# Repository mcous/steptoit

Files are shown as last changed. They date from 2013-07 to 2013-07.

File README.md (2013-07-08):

# Stepper Driver Board

## Parts to research / use
* Stepper driver - TI DRV8834
    * Up to 1/32 microstepping
    * 1.5 A continuous, 2.2 A peak
    * Step / direction control
    * Digikey qty 1: QFN: $2.98, TSOP: $3.53
* MCU - AVR ATMega328P
    * Cheap, simple, known
    * Probably underpowered in the long term
    * Tops out (apparently) at 16 MHz, and would like to go faster
* Steppers
    * check out http://www.mpja.com/
    * Start small

## To-do list
* Finalize(ish) parts list
* Design stepper control board
* Order stepper control board
* Order parts
* Design stepper testing frame
    * Three-axis linear movement table?
    * Three DOF rotational frame?
* Build stepper frame
* Assemble control board
* ???
* Profit!

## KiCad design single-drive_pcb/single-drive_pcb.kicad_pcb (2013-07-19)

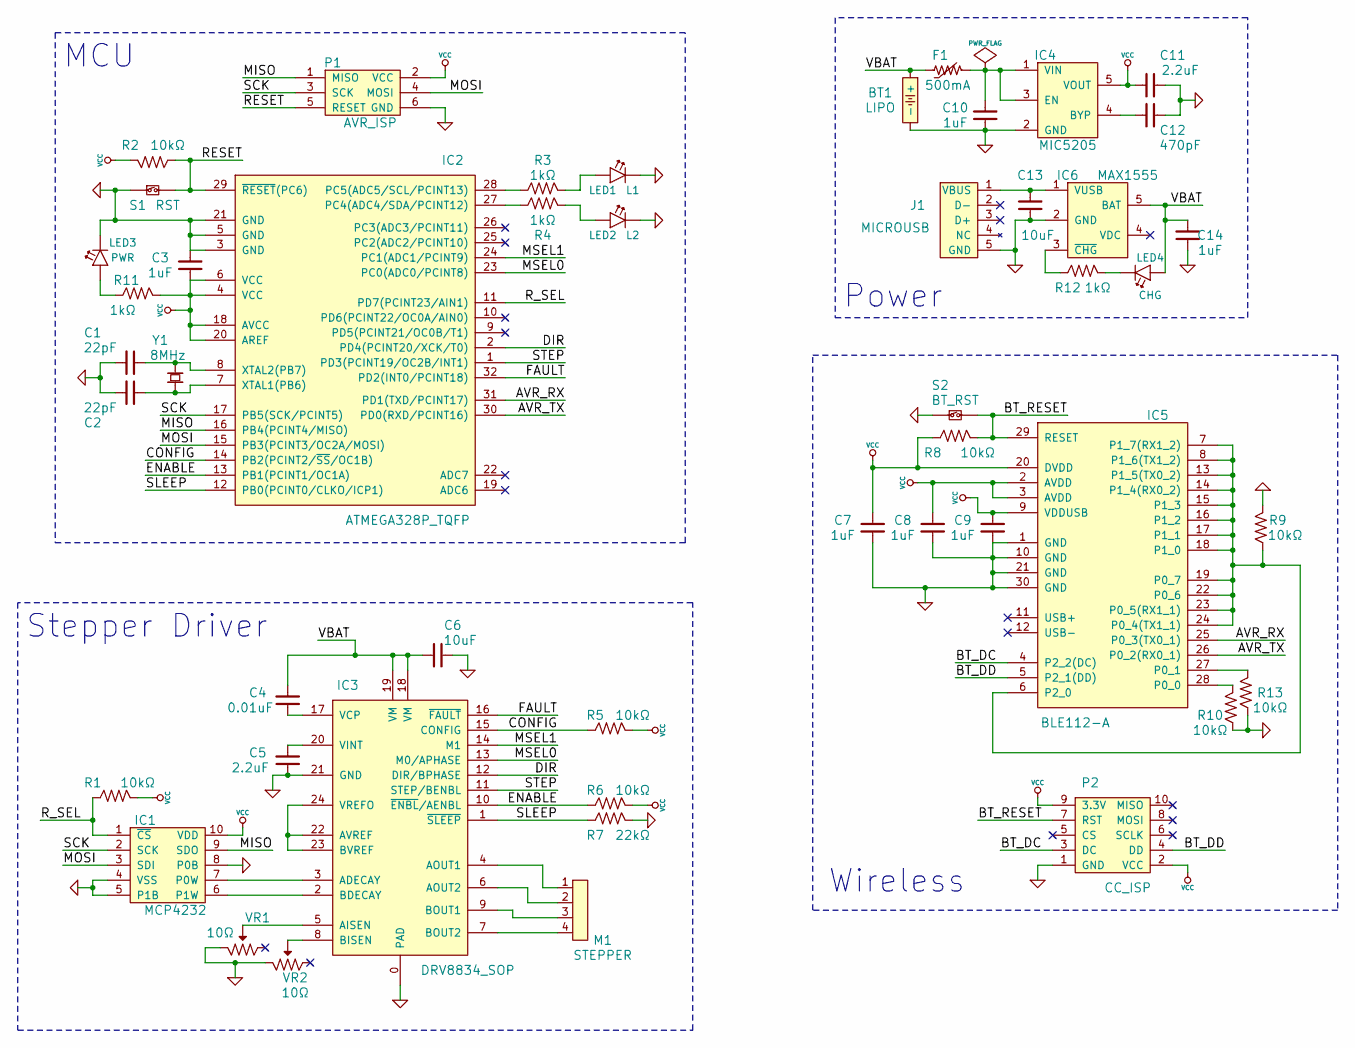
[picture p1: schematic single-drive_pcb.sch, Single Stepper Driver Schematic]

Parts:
BT1: LIPO
C1, C2: 22pF
C3, C7, C8, C9, C10, C14: 1uF
C4: 0.01uF
C5, C11: 2.2uF
C6, C13: 10uF
C12: 470pF
F1: 500mA
IC1: MCP4232
IC2: ATMEGA328P_TQFP
IC3: DRV8834_SOP
IC4: MIC5205
IC5: BLE112-A
IC6: MAX1555
J1: MICROUSB
LED1: L1
LED2: L2
LED3: PWR
LED4: CHG
M1: STEPPER
P1: AVR_ISP
P2: CC_ISP
R1, R2, R5, R6, R8, R9, R10, R13: 10kΩ
R3, R4, R11, R12: 1kΩ
R7: 22kΩ
S1: RST
S2: BT_RST
VR1, VR2: 10Ω
Y1: 8MHz

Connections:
/AVR_RX: IC2.31 (PD1(TXD/PCINT17)), IC5.25 (P0_3(TX0_1))
/AVR_TX: IC2.30 (PD0(RXD/PCINT16)), IC5.26 (P0_2(RX0_1))
/BT_DC: IC5.4 (P2_2(DC)), P2.3 (DC)
/BT_DD: IC5.5 (P2_1(DD)), P2.4 (DD)
/BT_RESET: IC5.29 (RESET), P2.7 (RST), R8.2, S2.2
/CONFIG: IC2.14 (PB2(PCINT2/~SS~/OC1B)), IC3.15 (CONFIG), R5.1
/DIR: IC2.2 (PD4(PCINT20/XCK/T0)), IC3.12 (DIR/BPHASE)
/ENABLE: IC2.13 (PB1(PCINT1/OC1A)), IC3.10 (~ENBL~/AENBL), R6.1
/FAULT: IC2.32 (PD2(INT0/PCINT18)), IC3.16 (~FAULT~)
/MISO: IC1.9 (SDO), IC2.16 (PB4(PCINT4/MISO)), P1.1 (MISO)
/MOSI: IC1.3 (SDI), IC2.15 (PB3(PCINT3/OC2A/MOSI)), P1.4 (MOSI)
/MSEL0: IC2.23 (PC0(ADC0/PCINT8)), IC3.13 (M0/APHASE)
/MSEL1: IC2.24 (PC1(ADC1/PCINT9)), IC3.14 (M1)
/RESET: IC2.29 (~RESET~(PC6)), P1.5 (RESET), R2.1, S1.2
/R_SEL: IC1.1 (~CS~), IC2.11 (PD7(PCINT23/AIN1)), R1.1
/SCK: IC1.2 (SCK), IC2.17 (PB5(SCK/PCINT5)), P1.3 (SCK)
/SLEEP: IC2.12 (PB0(PCINT0/CLKO/ICP1)), IC3.1 (~SLEEP~), R7.1
/STEP: IC2.1 (PD3(PCINT19/OC2B/INT1)), IC3.11 (STEP/BENBL)
/VBAT: BT1.1 (+), C4.1, C6.1, C14.2, F1.1, IC3.18 (VM), IC3.19 (VM), IC6.5 (BAT), LED4.2 (A)
GND: BT1.2 (-), C1.2, C2.1, C3.2, C5.1, C6.2, C7.1, C8.1, C9.1, C10.1, C11.2, C12.2, C13.1, C14.1, IC1.4 (VSS), IC1.5 (P1B), IC1.8 (P0B), IC2.3 (GND), IC2.5 (GND), IC2.21 (GND), IC3.0 (PAD), IC3.21 (GND), IC4.2 (GND), IC5.1 (GND), IC5.10 (GND), IC5.21 (GND), IC5.30 (GND), IC6.2 (GND), J1.5 (GND), LED1.1 (C), LED2.1 (C), LED3.1 (C), P1.6 (GND), P2.1 (GND), R7.2, R9.2, R10.1, R13.1, S1.1, S2.1, VR1.3 (E2), VR2.3 (E2)
unnamed: LED4.1 (C), R12.2
unnamed: C13.2, IC6.1 (VUSB), J1.1 (VBUS)
unnamed: IC3.7 (BOUT2), M1.4
unnamed: C10.2, F1.2, IC4.1 (VIN), IC4.3 (EN)
unnamed: LED3.2 (A), R11.1
unnamed: IC3.22 (AVREF), IC3.23 (BVREF), IC3.24 (VREFO)
unnamed: IC6.3 (~CHG~), R12.1
unnamed: C4.2, IC3.17 (VCP)
unnamed: C5.2, IC3.20 (VINT)
unnamed: IC3.9 (BOUT1), M1.3
unnamed: IC3.4 (AOUT1), M1.1
unnamed: C12.1, IC4.4 (BYP)
unnamed: IC5.27 (P0_1), R13.2
unnamed: IC3.6 (AOUT2), M1.2
unnamed: IC5.28 (P0_0), R10.2
unnamed: IC1.7 (P0W), IC3.3 (ADECAY)
unnamed: IC1.6 (P1W), IC3.2 (BDECAY)
unnamed: IC3.5 (AISEN), VR1.2 (W)
unnamed: IC3.8 (BISEN), VR2.2 (W)
unnamed: IC2.28 (PC5(ADC5/SCL/PCINT13)), R3.1
unnamed: IC2.27 (PC4(ADC4/SDA/PCINT12)), R4.1
unnamed: LED2.2 (A), R4.2
unnamed: LED1.2 (A), R3.2
unnamed: IC5.6 (P2_0), IC5.7 (P1_7(RX1_2)), IC5.8 (P1_6(TX1_2)), IC5.13 (P1_5(TX0_2)), IC5.14 (P1_4(RX0_2)), IC5.15 (P1_3), IC5.16 (P1_2), IC5.17 (P1_1), IC5.18 (P1_0), IC5.19 (P0_7), IC5.22 (P0_6), IC5.23 (P0_5(RX1_1)), IC5.24 (P0_4(TX1_1)), R9.1
unnamed: C1.1, IC2.8 (XTAL2(PB7)), Y1.2
unnamed: C2.2, IC2.7 (XTAL1(PB6)), Y1.1
VCC: C3.1, C7.2, C8.2, C9.2, C11.1, IC1.10 (VDD), IC2.4 (VCC), IC2.6 (VCC), IC2.18 (AVCC), IC2.20 (AREF), IC4.5 (VOUT), IC5.2 (AVDD), IC5.3 (AVDD), IC5.9 (VDDUSB), IC5.20 (DVDD), P1.2 (VCC), P2.2 (VCC), P2.9 (3.3V), R1.2, R2.2, R5.2, R6.2, R8.1, R11.2

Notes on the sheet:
Power
Wireless
MCU
Stepper Driver

Board: 2 copper layers, 48 parts (0 on the bottom side), 47 nets, no tracks yet.

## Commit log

2013-07-12 pcb files for first stepper project
    [single-drive_pcb.kicad_pcb, single-drive_pcb.sch]
2013-07-12 added most of the components to the schematic and did some basic wiring
    [single-drive_pcb.sch]
2013-07-18 refactored schematic for wirelessly controlled battery powered application
    [single-drive_pcb.sch]
2013-07-19 added gitignore to ignore some temp kicad stuff my global doesn't catch
2013-07-19 added some pots to stepper current control
2013-07-19 schematic coming along
    [single-drive_pcb.sch]
2013-07-19 schematic is done (until I find problems); moving on to footprint assignment
    [single-drive_pcb.sch]
2013-07-19 hey, remember that time I completely forgot to add a charging circuit to my battery powered project?
    [single-drive_pcb.sch]
2013-07-19 added comonent to footprint file
2013-07-19 schematic done and footprints assigned
    [single-drive_pcb.sch]
2013-07-19 started on pcb layout, need some dimensions before continuing
    [single-drive_pcb.kicad_pcb, single-drive_pcb.sch]

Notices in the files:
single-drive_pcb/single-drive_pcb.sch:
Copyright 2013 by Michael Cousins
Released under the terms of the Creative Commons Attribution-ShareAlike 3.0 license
